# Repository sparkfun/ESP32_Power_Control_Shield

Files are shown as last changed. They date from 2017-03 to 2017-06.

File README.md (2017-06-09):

ESP32 Thing Power Control Shield
=======

Power Control Shield

*[SparkFun ESP32 Thing Power Control Shield](https://www.sparkfun.com/products/14155)*

The ESP32 Thing Power Control Shield is a small adapter board for the [ESP32 Thing](https://www.sparkfun.com/products/13907). The shield gives the ESP32 Thing the power to switch loads of up to 5A between 5 and 28VDC. The shield has 6 output pins to connect loads to, and three current sensors connected to outputs 2, 4, and 6. Operational amplifiers are by default configured as voltage followers, but feedback resistors are broken out to increase the gain of the non-inverting op-amp, which allows for greater precision depending on the maximum expected loads. 

Repository Contents
-------------------

* **/Production** - Panelized version of the design for production
* **/Hardware** - All Eagle design files (.brd, .sch)

License Information
-------------------

This design is [OSHW](http://www.oshwa.org/definition/) and public domain but you buy me a beer if you use this and we meet someday ([Beerware license](http://en.wikipedia.org/wiki/Beerware)).

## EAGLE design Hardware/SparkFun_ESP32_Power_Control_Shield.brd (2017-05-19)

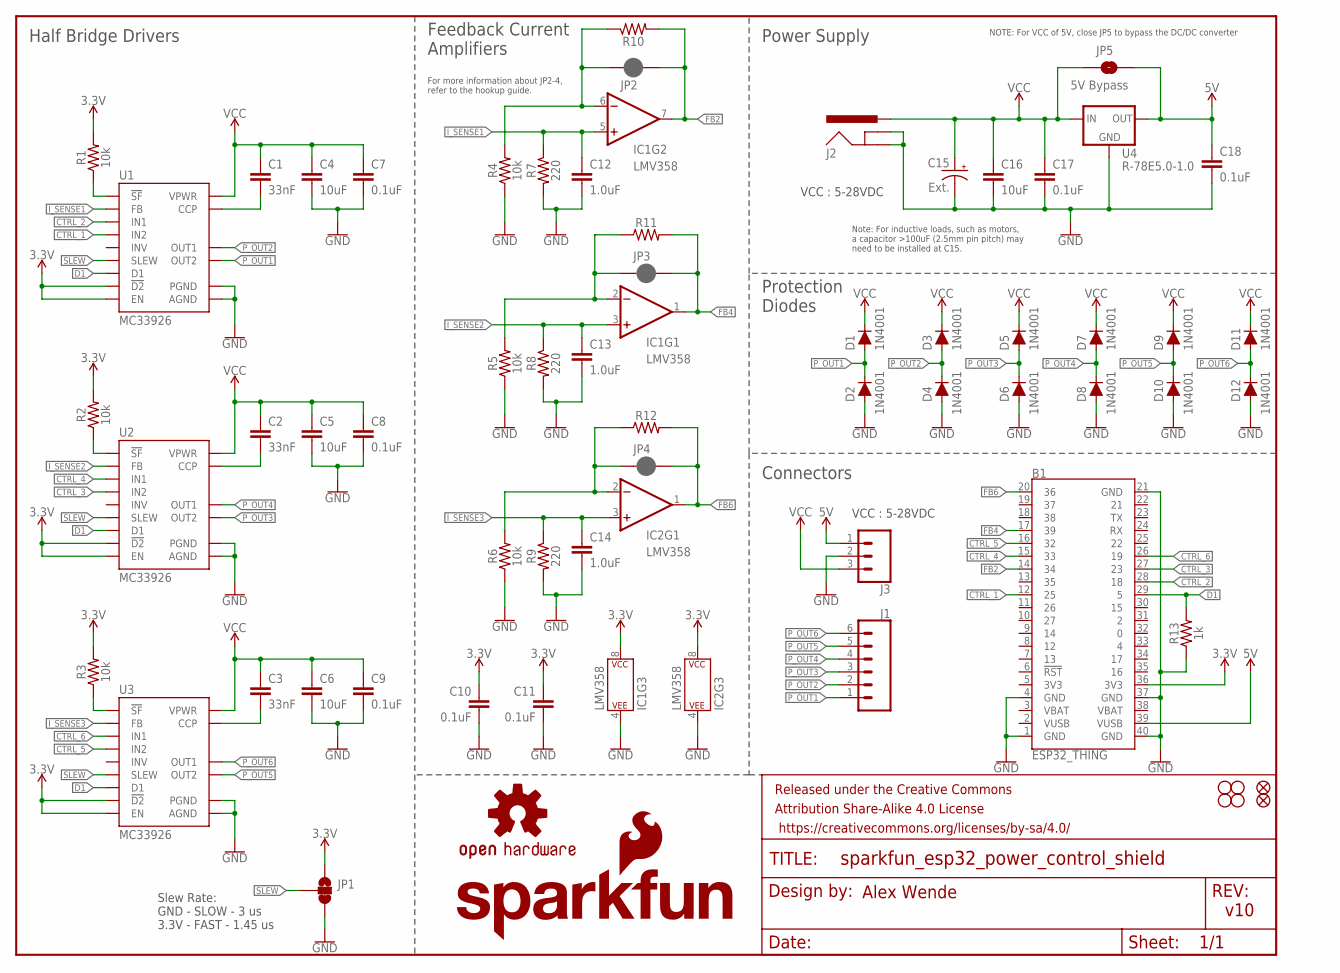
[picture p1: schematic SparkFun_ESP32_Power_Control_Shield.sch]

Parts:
B1: ESP32_THING
C1, C2, C3: 33nF; 0603
C4, C5, C6, C16: 10uF; 1210
C7, C8, C9, C10, C11, C17, C18: 0.1uF; 0603
C12, C13, C14: 1.0uF; 0603
C15: Ext.; CPOL-RADIAL-2.5MM-6.5MM
D1, D2, D3, D4, D5, D6, D7, D8, D9, D10, D11, D12: 1N4001; DIODE-1N4001
FD1, FD2: FIDUCIALUFIDUCIAL; FIDUCIAL-MICRO
FRAME1: FRAME-LETTER; CREATIVE_COMMONS
H1, H2, H3, H4: STAND-OFF
IC1, IC2: LMV358; SO08
J1: CONN_063.5MM-6; SCREWTERMINAL-3.5MM-6
J2: POWER_JACKPTH_LOCK; POWER_JACK_PTH_LOCK
J3: CONN_03SCREW; SCREWTERMINAL-3.5MM-3
JP1: JUMPER-SMT_3_1-NC_TRACE_SILK; SMT-JUMPER_3_1-NC_TRACE_SILK
JP2, JP3, JP4: JUMPER-SMT_2_NC_PASTE_NO-SILK; SMT-JUMPER_2_NC_PASTE_NO-SILK
JP5: 5V Bypass; SMT-JUMPER_2_NO_SILK
LOGO1: SFE_LOGO_NAME_FLAME.2_INCH; SFE_LOGO_NAME_FLAME_.2
LOGO2: OSHW-LOGOM; OSHW-LOGO-M
R1, R2, R3, R4, R5, R6: 10k; 0603
R7, R8, R9: 220; 0603
R10, R11, R12: 1KOHM-HORIZ-1/4W-1%; AXIAL-0.3
R13: 1k; 0603
U1, U2, U3: MC33926; 32-PQFN
U4: R-78E5.0-1.0; DC-DC_CONVERTER_78XX

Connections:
3.3V: B1.36 (3V3), C10.1, C11.1, IC1.8 (P$V+), IC2.8 (P$V+), JP1.1, R1.2, R2.2, R3.2, U1.P$10 (EN), U1.P$16 (!D2), U2.P$10 (EN), U2.P$16 (!D2), U3.P$10 (EN), U3.P$16 (!D2)
5V: B1.39 (VUSB), C18.1, J3.1, JP5.2, U4.VOUT (OUT)
CTRL_1: B1.12 (25), U1.P$1 (IN2)
CTRL_2: B1.28 (18), U1.P$2 (IN1)
CTRL_3: B1.27 (23), U2.P$1 (IN2)
CTRL_4: B1.15 (33), U2.P$2 (IN1)
CTRL_5: B1.16 (32), U3.P$1 (IN2)
CTRL_6: B1.26 (19), U3.P$2 (IN1)
D1: B1.29 (5), R13.2, U1.P$26 (D1), U2.P$26 (D1), U3.P$26 (D1)
FB2: B1.14 (34), IC1.7 (OUT), JP2.2, R10.P$2 (2)
FB4: B1.17 (39), IC1.1 (OUT), JP3.2, R11.P$2 (2)
FB6: B1.20 (36), IC2.1 (OUT), JP4.2, R12.P$2 (2)
GND: B1.1 (GND), B1.4 (GND), B1.21 (GND), B1.37 (GND), B1.40 (GND), C4.2, C5.2, C6.2, C7.2, C8.2, C9.2, C10.2, C11.2, C12.2, C13.2, C14.2, C15.2 (-), C16.2, C17.2, C18.2, D2.A, D4.A, D6.A, D8.A, D10.A, D12.A, IC1.4 (P$V-), IC2.4 (P$V-), J2.GND, J2.GNDBREAK, J3.2, JP1.3, R4.1, R5.1, R6.1, R7.2, R8.2, R9.2, R13.1, U1.P$5 (AGND), U1.P$18 (PGND), U1.P$19 (PGND), U1.P$20 (PGND), U1.P$22 (PGND), U1.P$23 (PGND), U1.P$24 (PGND), U1.P$33 (AGND), U2.P$5 (AGND), U2.P$18 (PGND), U2.P$19 (PGND), U2.P$20 (PGND), U2.P$22 (PGND), U2.P$23 (PGND), U2.P$24 (PGND), U2.P$33 (AGND), U3.P$5 (AGND), U3.P$18 (PGND), U3.P$19 (PGND), U3.P$20 (PGND), U3.P$22 (PGND), U3.P$23 (PGND), U3.P$24 (PGND), U3.P$33 (AGND), U4.GND
I_SENSE1: C12.1, IC1.5 (+IN), R7.1, U1.P$8 (FB)
I_SENSE2: C13.1, IC1.3 (+IN), R8.1, U2.P$8 (FB)
I_SENSE3: C14.1, IC2.3 (+IN), R9.1, U3.P$8 (FB)
unnamed: IC1.6 (-IN), JP2.1, R4.2, R10.P$1 (1)
unnamed: IC2.2 (-IN), JP4.1, R6.2, R12.P$1 (1)
unnamed: IC1.2 (-IN), JP3.1, R5.2, R11.P$1 (1)
unnamed: R2.1, U2.P$21 (!SF)
unnamed: C2.2, U2.P$32 (CCP)
unnamed: R3.1, U3.P$21 (!SF)
unnamed: R1.1, U1.P$21 (!SF)
unnamed: C1.2, U1.P$32 (CCP)
unnamed: C3.2, U3.P$32 (CCP)
P_OUT1: D1.A, D2.C, J1.1, U1.P$27 (OUT2), U1.P$28 (OUT2), U1.P$29 (OUT2), U1.P$30 (OUT2)
P_OUT2: D3.A, D4.C, J1.2, U1.P$12 (OUT1), U1.P$13 (OUT1), U1.P$14 (OUT1), U1.P$15 (OUT1)
P_OUT3: D5.A, D6.C, J1.3, U2.P$27 (OUT2), U2.P$28 (OUT2), U2.P$29 (OUT2), U2.P$30 (OUT2)
P_OUT4: D7.A, D8.C, J1.4, U2.P$12 (OUT1), U2.P$13 (OUT1), U2.P$14 (OUT1), U2.P$15 (OUT1)
P_OUT5: D9.A, D10.C, J1.5, U3.P$27 (OUT2), U3.P$28 (OUT2), U3.P$29 (OUT2), U3.P$30 (OUT2)
P_OUT6: D11.A, D12.C, J1.6, U3.P$12 (OUT1), U3.P$13 (OUT1), U3.P$14 (OUT1), U3.P$15 (OUT1)
SLEW: JP1.2, U1.P$3 (SLEW), U2.P$3 (SLEW), U3.P$3 (SLEW)
VCC: C1.1, C2.1, C3.1, C4.1, C5.1, C6.1, C7.1, C8.1, C9.1, C15.1 (+), C16.1, C17.1, D1.C, D3.C, D5.C, D7.C, D9.C, D11.C, J2.PWR, J3.3, JP5.1, U1.P$4 (VPWR), U1.P$6 (VPWR), U1.P$11 (VPWR), U1.P$31 (VPWR), U2.P$4 (VPWR), U2.P$6 (VPWR), U2.P$11 (VPWR), U2.P$31 (VPWR), U3.P$4 (VPWR), U3.P$6 (VPWR), U3.P$11 (VPWR), U3.P$31 (VPWR), U4.VIN (IN)

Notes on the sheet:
Alex Wende
v10
Half Bridge Drivers
Feedback Current Amplifiers
Power Supply
Protection Diodes
Connectors
Slew Rate: GND - SLOW - 3 us 3.3V - FAST - 1.45 us
VCC : 5-28VDC
NOTE: For VCC of 5V, close JP5 to bypass the DC/DC converter
For more information about JP2-4, refer to the hookup guide.
Note: For inductive loads, such as motors, a capacitor >100uF (2.5mm pin pitch) may need to be installed at C15.

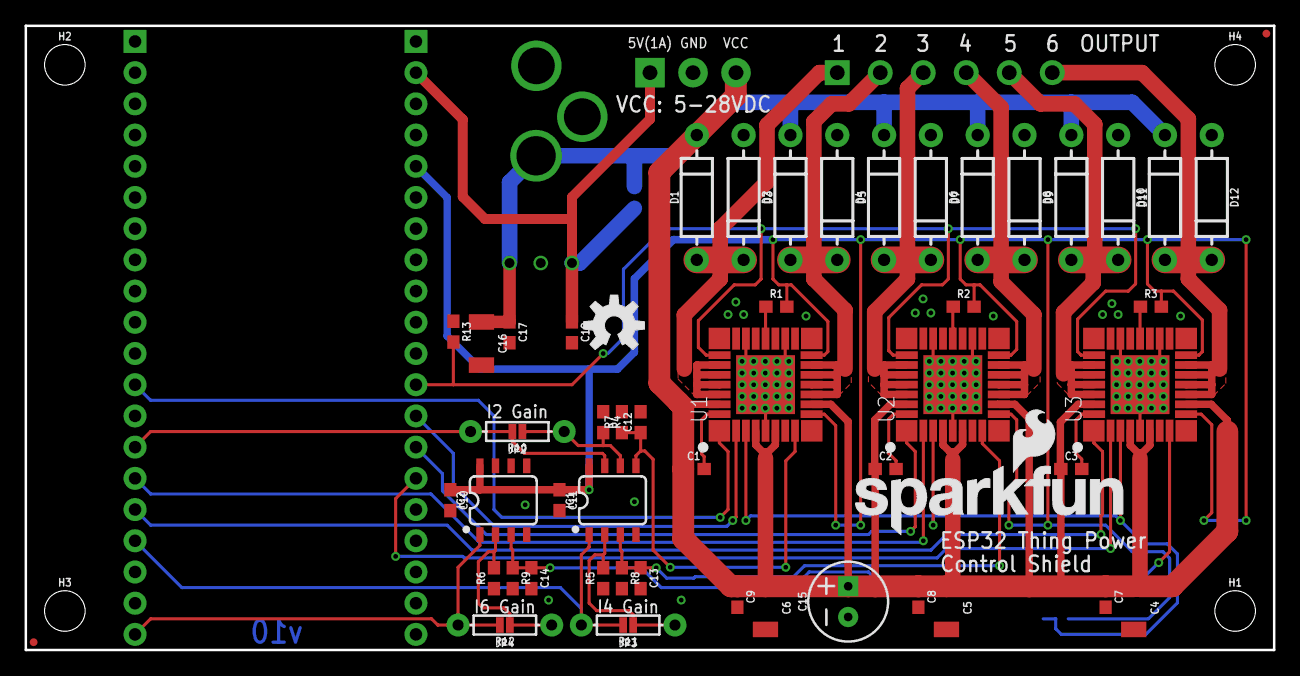
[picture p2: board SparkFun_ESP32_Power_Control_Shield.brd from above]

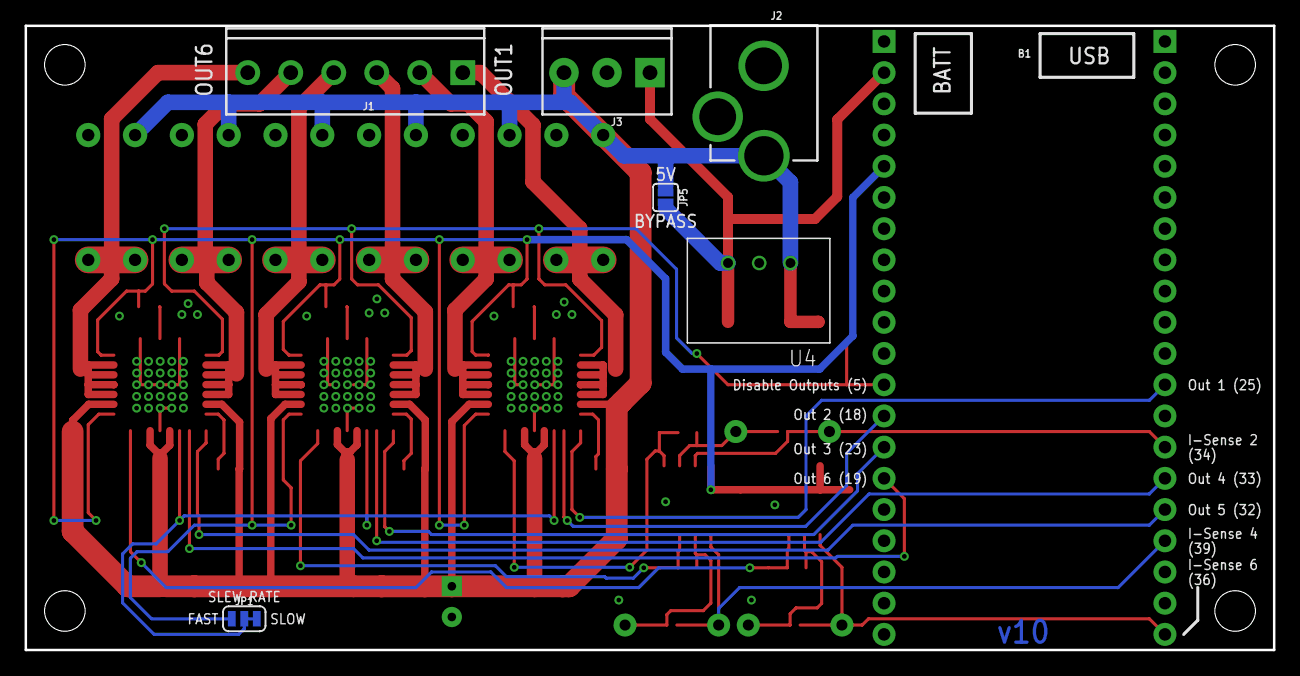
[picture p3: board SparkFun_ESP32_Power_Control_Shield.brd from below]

Board: 2 copper layers, 101.6 x 50.8 mm, 68 parts (7 on the bottom side), 33 nets.

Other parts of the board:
U$1: ORDERING_INSTRUCTIONS

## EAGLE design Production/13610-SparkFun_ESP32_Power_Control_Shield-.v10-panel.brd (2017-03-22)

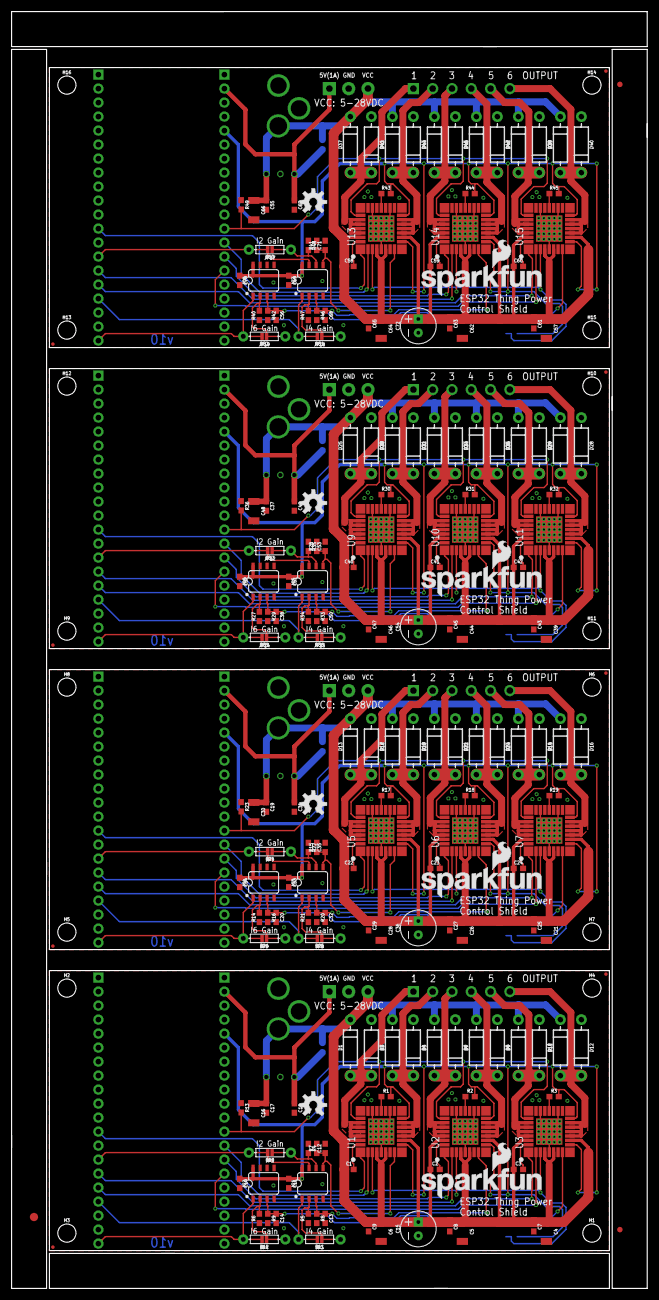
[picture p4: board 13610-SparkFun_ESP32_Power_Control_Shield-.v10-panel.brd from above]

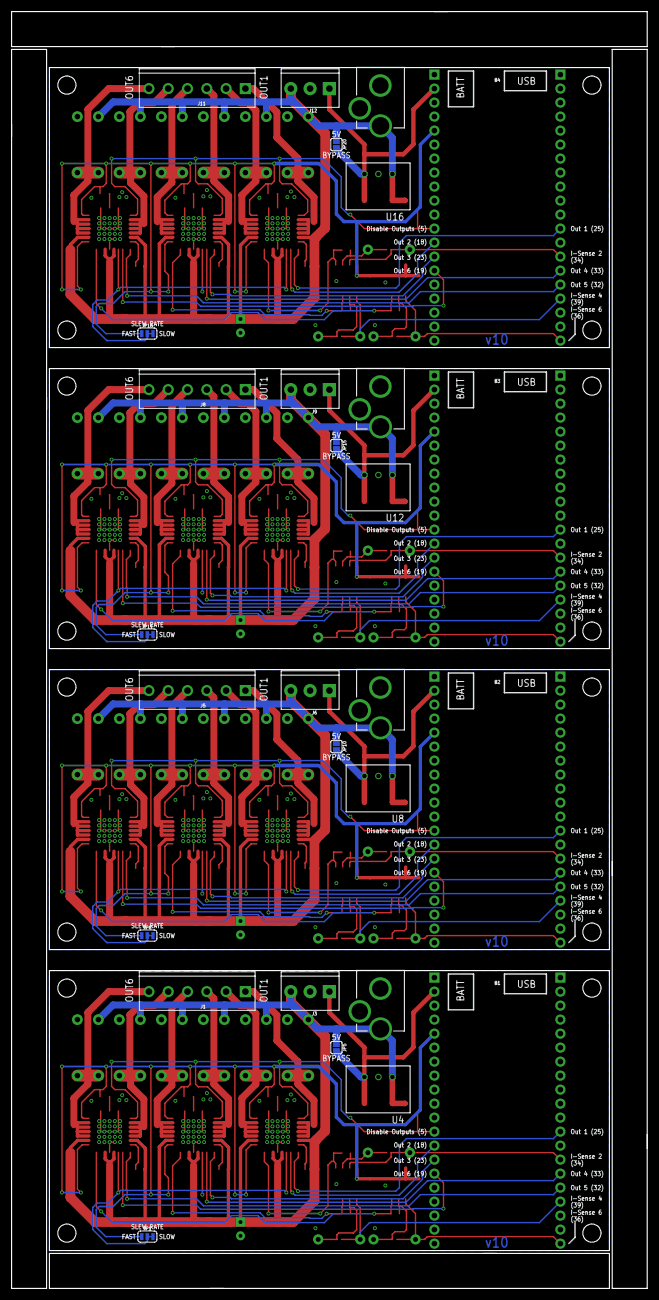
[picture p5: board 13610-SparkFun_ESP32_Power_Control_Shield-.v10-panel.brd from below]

Board: 2 copper layers, 115.3 x 231.6 mm, 267 parts (28 on the bottom side), 132 nets.

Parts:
B1, B2, B3, B4: ESP32_THING
C1, C2, C3, C22, C23, C24, C40, C41, C42, C58, C59, C60: 33nF; 0603
C4, C5, C6, C16, C21, C26, C28, C30, C39, C44, C46, C48, C57, C62, C64, C66: 10uF; 1210
C7, C8, C9, C10, C11, C17, C18, C19, C25, C27, C29, C31, C33, C34, C37, C43, C45, C47, C49, C51, C52, C55, C61, C63, C65, C67, C69, C70: 0.1uF; 0603
C12, C13, C14, C20, C32, C35, C38, C50, C53, C56, C68, C71: 1.0uF; 0603
C15, C36, C54, C72: Ext.; CPOL-RADIAL-2.5MM-6.5MM
D1, D2, D3, D4, D5, D6, D7, D8, D9, D10, D11, D12, D13, D14, D15, D16, D17, D18, D19, D20, D21, D22, D23, D24, D25, D26, D27, D28, D29, D30, D31, D32, D33, D34, D35, D36, D37, D38, D39, D40, D41, D42, D43, D44, D45, D46, D47, D48: 1N4001; DIODE-1N4001
E$1: FIDUCIAL-1.5X3
E$7, E$8: FIDUCIAL-1X2
FD1, FD2, FD3, FD4, FD5, FD6, FD7, FD8: FIDUCIALUFIDUCIAL; FIDUCIAL-MICRO
H1, H2, H3, H4, H5, H6, H7, H8, H9, H10, H11, H12, H13, H14, H15, H16: STAND-OFF
IC1, IC2, IC3, IC4, IC5, IC6, IC7, IC8: LMV358; SO08
J1, J5, J8, J11: SCREWTERMINAL-3.5MM-6
J2, J4, J7, J10: POWER_JACKPTH_LOCK; POWER_JACK_PTH_LOCK
J3, J6, J9, J12: SCREWTERMINAL-3.5MM-3
JP1, JP6, JP11, JP16: SMT-JUMPER_3_1-NC_TRACE_SILK
JP2, JP3, JP4, JP7, JP8, JP9, JP12, JP13, JP14, JP17, JP18, JP19: SMT-JUMPER_2_NC_PASTE_NO-SILK
JP5, JP10, JP15, JP20: 5V Bypass; SMT-JUMPER_2_NO_SILK
LOGO1, LOGO3, LOGO5, LOGO7: SFE_LOGO_NAME_FLAME.2_INCH; SFE_LOGO_NAME_FLAME_.2
LOGO2, LOGO4, LOGO6, LOGO8: OSHW-LOGOM; OSHW-LOGO-M
R1, R2, R3, R4, R5, R6, R13, R14, R17, R18, R19, R21, R22, R23, R27, R30, R31, R32, R34, R35, R36, R40, R43, R44, R45, R47, R48, R49: 10k; 0603
R7, R8, R9, R15, R16, R20, R28, R29, R33, R41, R42, R46: 220; 0603
R10, R11, R12, R24, R25, R26, R37, R38, R39, R50, R51, R52: AXIAL-0.3
U1, U2, U3, U5, U6, U7, U9, U10, U11, U13, U14, U15: MC33926; 32-PQFN
U4, U8, U12, U16: R-78E5.0-1.0; DC-DC_CONVERTER_78XX

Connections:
3.3V: B1.36, C10.1, C11.1, IC1.8, IC2.8, JP1.1, R1.2, R2.2, R3.2, U1.P$10, U1.P$16, U2.P$10, U2.P$16, U3.P$10, U3.P$16
3.3V1: B2.36, C33.1, C34.1, IC3.8, IC4.8, JP6.1, R17.2, R18.2, R19.2, U5.P$10, U5.P$16, U6.P$10, U6.P$16, U7.P$10, U7.P$16
3.3V2: B3.36, C51.1, C52.1, IC5.8, IC6.8, JP11.1, R30.2, R31.2, R32.2, U9.P$10, U9.P$16, U10.P$10, U10.P$16, U11.P$10, U11.P$16
3.3V3: B4.36, C69.1, C70.1, IC7.8, IC8.8, JP16.1, R43.2, R44.2, R45.2, U13.P$10, U13.P$16, U14.P$10, U14.P$16, U15.P$10, U15.P$16
5V: B1.39, C18.1, J3.1, JP5.2, U4.VOUT
5V1: B2.39, C31.1, J6.1, JP10.2, U8.VOUT
5V2: B3.39, C49.1, J9.1, JP15.2, U12.VOUT
5V3: B4.39, C67.1, J12.1, JP20.2, U16.VOUT
CTRL_1: B1.12, U1.P$1
CTRL_2: B1.28, U1.P$2
CTRL_3: B1.27, U2.P$1
CTRL_4: B1.15, U2.P$2
CTRL_5: B1.16, U3.P$1
CTRL_6: B1.26, U3.P$2
CTRL_7: B2.26, U7.P$2
CTRL_8: B2.16, U7.P$1
CTRL_9: B2.15, U6.P$2
CTRL_10: B2.27, U6.P$1
CTRL_11: B2.28, U5.P$2
CTRL_12: B2.12, U5.P$1
CTRL_13: B3.26, U11.P$2
CTRL_14: B3.16, U11.P$1
CTRL_15: B3.15, U10.P$2
CTRL_16: B3.27, U10.P$1
CTRL_17: B3.28, U9.P$2
CTRL_18: B3.12, U9.P$1
CTRL_19: B4.26, U15.P$2
CTRL_20: B4.16, U15.P$1
CTRL_21: B4.15, U14.P$2
CTRL_22: B4.27, U14.P$1
CTRL_23: B4.28, U13.P$2
CTRL_24: B4.12, U13.P$1
D1: B1.29, R13.2, U1.P$26, U2.P$26, U3.P$26
D2: B2.29, R23.2, U5.P$26, U6.P$26, U7.P$26
D3: B3.29, R36.2, U9.P$26, U10.P$26, U11.P$26
D4: B4.29, R49.2, U13.P$26, U14.P$26, U15.P$26
FB1: B2.20, IC4.1, JP9.2, R26.P$2
FB2: B1.14, IC1.7, JP2.2, R10.P$2
FB3: B2.17, IC3.1, JP8.2, R25.P$2
FB4: B1.17, IC1.1, JP3.2, R11.P$2
FB5: B2.14, IC3.7, JP7.2, R24.P$2
FB6: B1.20, IC2.1, JP4.2, R12.P$2
FB7: B3.20, IC6.1, JP14.2, R39.P$2
FB8: B3.17, IC5.1, JP13.2, R38.P$2
FB9: B3.14, IC5.7, JP12.2, R37.P$2
FB10: B4.20, IC8.1, JP19.2, R52.P$2
FB11: B4.17, IC7.1, JP18.2, R51.P$2
FB12: B4.14, IC7.7, JP17.2, R50.P$2
GND: B1.1, B1.4, B1.21, B1.37, B1.40, C4.2, C5.2, C6.2, C7.2, C8.2, C9.2, C10.2, C11.2, C12.2, C13.2, C14.2, C15.2, C16.2, C17.2, C18.2, D2.A, D4.A, D6.A, D8.A, D10.A, D12.A, IC1.4, IC2.4, J2.GND, J2.GNDBREAK, J3.2, JP1.3, R4.1, R5.1, R6.1, R7.2, R8.2, R9.2, R13.1, U1.P$5, U1.P$18, U1.P$19, U1.P$20, U1.P$22, U1.P$23, U1.P$24, U1.P$33, U2.P$5, U2.P$18, U2.P$19, U2.P$20, U2.P$22, U2.P$23, U2.P$24, U2.P$33, U3.P$5, U3.P$18, U3.P$19, U3.P$20, U3.P$22, U3.P$23, U3.P$24, U3.P$33, U4.GND
GND1: B2.1, B2.4, B2.21, B2.37, B2.40, C19.2, C20.2, C21.2, C25.2, C26.2, C27.2, C28.2, C29.2, C30.2, C31.2, C32.2, C33.2, C34.2, C35.2, C36.2, D14.A, D16.A, D17.A, D19.A, D21.A, D23.A, IC3.4, IC4.4, J4.GND, J4.GNDBREAK, J6.2, JP6.3, R14.1, R15.2, R16.2, R20.2, R21.1, R22.1, R23.1, U5.P$5, U5.P$18, U5.P$19, U5.P$20, U5.P$22, U5.P$23, U5.P$24, U5.P$33, U6.P$5, U6.P$18, U6.P$19, U6.P$20, U6.P$22, U6.P$23, U6.P$24, U6.P$33, U7.P$5, U7.P$18, U7.P$19, U7.P$20, U7.P$22, U7.P$23, U7.P$24, U7.P$33, U8.GND
GND2: B3.1, B3.4, B3.21, B3.37, B3.40, C37.2, C38.2, C39.2, C43.2, C44.2, C45.2, C46.2, C47.2, C48.2, C49.2, C50.2, C51.2, C52.2, C53.2, C54.2, D26.A, D28.A, D29.A, D31.A, D33.A, D35.A, IC5.4, IC6.4, J7.GND, J7.GNDBREAK, J9.2, JP11.3, R27.1, R28.2, R29.2, R33.2, R34.1, R35.1, R36.1, U9.P$5, U9.P$18, U9.P$19, U9.P$20, U9.P$22, U9.P$23, U9.P$24, U9.P$33, U10.P$5, U10.P$18, U10.P$19, U10.P$20, U10.P$22, U10.P$23, U10.P$24, U10.P$33, U11.P$5, U11.P$18, U11.P$19, U11.P$20, U11.P$22, U11.P$23, U11.P$24, U11.P$33, U12.GND
GND3: B4.1, B4.4, B4.21, B4.37, B4.40, C55.2, C56.2, C57.2, C61.2, C62.2, C63.2, C64.2, C65.2, C66.2, C67.2, C68.2, C69.2, C70.2, C71.2, C72.2, D38.A, D40.A, D41.A, D43.A, D45.A, D47.A, IC7.4, IC8.4, J10.GND, J10.GNDBREAK, J12.2, JP16.3, R40.1, R41.2, R42.2, R46.2, R47.1, R48.1, R49.1, U13.P$5, U13.P$18, U13.P$19, U13.P$20, U13.P$22, U13.P$23, U13.P$24, U13.P$33, U14.P$5, U14.P$18, U14.P$19, U14.P$20, U14.P$22, U14.P$23, U14.P$24, U14.P$33, U15.P$5, U15.P$18, U15.P$19, U15.P$20, U15.P$22, U15.P$23, U15.P$24, U15.P$33, U16.GND
I_SENSE1: C12.1, IC1.5, R7.1, U1.P$8
I_SENSE2: C13.1, IC1.3, R8.1, U2.P$8
I_SENSE3: C14.1, IC2.3, R9.1, U3.P$8
I_SENSE4: C35.1, IC3.5, R15.1, U5.P$8
I_SENSE5: C32.1, IC3.3, R20.1, U6.P$8
I_SENSE6: C20.1, IC4.3, R16.1, U7.P$8
I_SENSE7: C53.1, IC5.5, R28.1, U9.P$8
I_SENSE8: C50.1, IC5.3, R33.1, U10.P$8
I_SENSE9: C38.1, IC6.3, R29.1, U11.P$8
I_SENSE10: C71.1, IC7.5, R41.1, U13.P$8
I_SENSE11: C68.1, IC7.3, R46.1, U14.P$8
I_SENSE12: C56.1, IC8.3, R42.1, U15.P$8
unnamed: R17.1, U5.P$21
unnamed: IC1.6, JP2.1, R4.2, R10.P$1
unnamed: C22.2, U5.P$32
unnamed: IC2.2, JP4.1, R6.2, R12.P$1
unnamed: IC1.2, JP3.1, R5.2, R11.P$1
unnamed: R2.1, U2.P$21
unnamed: C2.2, U2.P$32
unnamed: R18.1, U6.P$21
unnamed: R3.1, U3.P$21
unnamed: R1.1, U1.P$21
unnamed: C1.2, U1.P$32
unnamed: C3.2, U3.P$32
unnamed: C23.2, U6.P$32
unnamed: R19.1, U7.P$21
unnamed: C24.2, U7.P$32
unnamed: IC3.2, JP8.1, R21.2, R25.P$1
unnamed: IC3.6, JP7.1, R22.2, R24.P$1
unnamed: IC4.2, JP9.1, R14.2, R26.P$1
unnamed: R30.1, U9.P$21
unnamed: C40.2, U9.P$32
unnamed: R31.1, U10.P$21
unnamed: C41.2, U10.P$32
unnamed: R32.1, U11.P$21
unnamed: C42.2, U11.P$32
unnamed: IC5.2, JP13.1, R34.2, R38.P$1
unnamed: IC5.6, JP12.1, R35.2, R37.P$1
unnamed: IC6.2, JP14.1, R27.2, R39.P$1
unnamed: R43.1, U13.P$21
unnamed: C58.2, U13.P$32
unnamed: R44.1, U14.P$21
unnamed: C59.2, U14.P$32
unnamed: R45.1, U15.P$21
unnamed: C60.2, U15.P$32
unnamed: IC7.2, JP18.1, R47.2, R51.P$1
unnamed: IC7.6, JP17.1, R48.2, R50.P$1
unnamed: IC8.2, JP19.1, R40.2, R52.P$1
P_OUT1: D1.A, D2.C, J1.1, U1.P$27, U1.P$28, U1.P$29, U1.P$30
P_OUT2: D3.A, D4.C, J1.2, U1.P$12, U1.P$13, U1.P$14, U1.P$15
P_OUT3: D5.A, D6.C, J1.3, U2.P$27, U2.P$28, U2.P$29, U2.P$30
P_OUT4: D7.A, D8.C, J1.4, U2.P$12, U2.P$13, U2.P$14, U2.P$15
P_OUT5: D9.A, D10.C, J1.5, U3.P$27, U3.P$28, U3.P$29, U3.P$30
P_OUT6: D11.A, D12.C, J1.6, U3.P$12, U3.P$13, U3.P$14, U3.P$15
P_OUT7: D18.A, D19.C, J5.2, U5.P$12, U5.P$13, U5.P$14, U5.P$15
P_OUT8: D22.A, D23.C, J5.4, U6.P$12, U6.P$13, U6.P$14, U6.P$15
P_OUT9: D15.A, D16.C, J5.6, U7.P$12, U7.P$13, U7.P$14, U7.P$15
P_OUT10: D13.A, D17.C, J5.1, U5.P$27, U5.P$28, U5.P$29, U5.P$30
P_OUT11: D14.C, D24.A, J5.5, U7.P$27, U7.P$28, U7.P$29, U7.P$30
P_OUT12: D20.A, D21.C, J5.3, U6.P$27, U6.P$28, U6.P$29, U6.P$30
P_OUT13: D30.A, D31.C, J8.2, U9.P$12, U9.P$13, U9.P$14, U9.P$15
P_OUT14: D34.A, D35.C, J8.4, U10.P$12, U10.P$13, U10.P$14, U10.P$15
P_OUT15: D27.A, D28.C, J8.6, U11.P$12, U11.P$13, U11.P$14, U11.P$15
P_OUT16: D25.A, D29.C, J8.1, U9.P$27, U9.P$28, U9.P$29, U9.P$30
P_OUT17: D26.C, D36.A, J8.5, U11.P$27, U11.P$28, U11.P$29, U11.P$30
P_OUT18: D32.A, D33.C, J8.3, U10.P$27, U10.P$28, U10.P$29, U10.P$30
P_OUT19: D42.A, D43.C, J11.2, U13.P$12, U13.P$13, U13.P$14, U13.P$15
P_OUT20: D46.A, D47.C, J11.4, U14.P$12, U14.P$13, U14.P$14, U14.P$15
P_OUT21: D39.A, D40.C, J11.6, U15.P$12, U15.P$13, U15.P$14, U15.P$15
P_OUT22: D37.A, D41.C, J11.1, U13.P$27, U13.P$28, U13.P$29, U13.P$30
P_OUT23: D38.C, D48.A, J11.5, U15.P$27, U15.P$28, U15.P$29, U15.P$30
P_OUT24: D44.A, D45.C, J11.3, U14.P$27, U14.P$28, U14.P$29, U14.P$30
SLEW: JP1.2, U1.P$3, U2.P$3, U3.P$3
SLEW1: JP6.2, U5.P$3, U6.P$3, U7.P$3
SLEW2: JP11.2, U9.P$3, U10.P$3, U11.P$3
SLEW3: JP16.2, U13.P$3, U14.P$3, U15.P$3
VCC: C1.1, C2.1, C3.1, C4.1, C5.1, C6.1, C7.1, C8.1, C9.1, C15.1, C16.1, C17.1, D1.C, D3.C, D5.C, D7.C, D9.C, D11.C, J2.PWR, J3.3, JP5.1, U1.P$4, U1.P$6, U1.P$11, U1.P$31, U2.P$4, U2.P$6, U2.P$11, U2.P$31, U3.P$4, U3.P$6, U3.P$11, U3.P$31, U4.VIN
VCC1: C19.1, C21.1, C22.1, C23.1, C24.1, C25.1, C26.1, C27.1, C28.1, C29.1, C30.1, C36.1, D13.C, D15.C, D18.C, D20.C, D22.C, D24.C, J4.PWR, J6.3, JP10.1, U5.P$4, U5.P$6, U5.P$11, U5.P$31, U6.P$4, U6.P$6, U6.P$11, U6.P$31, U7.P$4, U7.P$6, U7.P$11, U7.P$31, U8.VIN
VCC2: C37.1, C39.1, C40.1, C41.1, C42.1, C43.1, C44.1, C45.1, C46.1, C47.1, C48.1, C54.1, D25.C, D27.C, D30.C, D32.C, D34.C, D36.C, J7.PWR, J9.3, JP15.1, U9.P$4, U9.P$6, U9.P$11, U9.P$31, U10.P$4, U10.P$6, U10.P$11, U10.P$31, U11.P$4, U11.P$6, U11.P$11, U11.P$31, U12.VIN
VCC3: C55.1, C57.1, C58.1, C59.1, C60.1, C61.1, C62.1, C63.1, C64.1, C65.1, C66.1, C72.1, D37.C, D39.C, D42.C, D44.C, D46.C, D48.C, J10.PWR, J12.3, JP20.1, U13.P$4, U13.P$6, U13.P$11, U13.P$31, U14.P$4, U14.P$6, U14.P$11, U14.P$31, U15.P$4, U15.P$6, U15.P$11, U15.P$31, U16.VIN

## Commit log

2017-01-30 Initial Commit
    Initial layout for the SparkFun ESP32 Thing Power Control Shield.
    [SparkFun_ESP32_Power_Control_Shield.brd, SparkFun_ESP32_Power_Control_Shield.sch]
2017-01-30 Added measurements for board size and version number
    [SparkFun_ESP32_Power_Control_Shield.brd, SparkFun_ESP32_Power_Control_Shield.sch]
2017-01-30 Added external capacitor
    External capacitor will be populated by end user if too much ripple is
    present on power rail.
    [SparkFun_ESP32_Power_Control_Shield.brd, SparkFun_ESP32_Power_Control_Shield.sch]
2017-02-01 Proto design review changes
    - Replaced SMD barrel jack with PTH
    - Replaced op-amp resistor with 15k resistor
    - Moved IO away from pins 34-39
    - Attached disable input pin to IO pin
    - Replaced 3/4 2-pin screw terminals with 6-pin screw terminal
    - Added labeling to all IO pins used
    [SparkFun_ESP32_Power_Control_Shield.brd, SparkFun_ESP32_Power_Control_Shield.sch]
2017-02-01 Same changes as design review
    Forgot to save changes before commit.
    [SparkFun_ESP32_Power_Control_Shield.brd, SparkFun_ESP32_Power_Control_Shield.sch]
2017-02-01 QC Fixes
    Replaced 0.1uF capacitors CAP-00810 with CAP-08390
    [SparkFun_ESP32_Power_Control_Shield.brd, SparkFun_ESP32_Power_Control_Shield.sch]
2017-03-08 v10 Changes
    - Flipped connectors from top layer to bottom
    - Replaced 2-pin power connector with a 3-pin. Additional pin breaks out
    5V power rail for a 5VDC fan.
    - Added pull-down resistor to disable output (enabled by default).
    - Replaced 5V LDO with DC/DC converter
    - Replaced 240ohm resistors with 220ohm
    - Replaced 15k feedback resistors with solder jumper and unpopulated PTH
    resistor
    - Increased trace width on VCC rail
    - Added 5V bypass jumper to bypass the DC/DC converter which has a
    minimum input voltage of 7V.
    [SparkFun_ESP32_Power_Control_Shield.brd, SparkFun_ESP32_Power_Control_Shield.sch]
2017-03-10 v10 changes additional
    minor schematic layout changes, added values for the op-amps and diodes.
    [SparkFun_ESP32_Power_Control_Shield.brd, SparkFun_ESP32_Power_Control_Shield.sch]
2017-03-10 Added PROD_ID to DC/DC Converter
    [SparkFun_ESP32_Power_Control_Shield.brd, SparkFun_ESP32_Power_Control_Shield.sch]
2017-05-19 Replaced R13
    Pull down resistor R13 was too weak for the ESP32 at 10k. Replacing with
    1k.
    [SparkFun_ESP32_Power_Control_Shield.brd, SparkFun_ESP32_Power_Control_Shield.sch]

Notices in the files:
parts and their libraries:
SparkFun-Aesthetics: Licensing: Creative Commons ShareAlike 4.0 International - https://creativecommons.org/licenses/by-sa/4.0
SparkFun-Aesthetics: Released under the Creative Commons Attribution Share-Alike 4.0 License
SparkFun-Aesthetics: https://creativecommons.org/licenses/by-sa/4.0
